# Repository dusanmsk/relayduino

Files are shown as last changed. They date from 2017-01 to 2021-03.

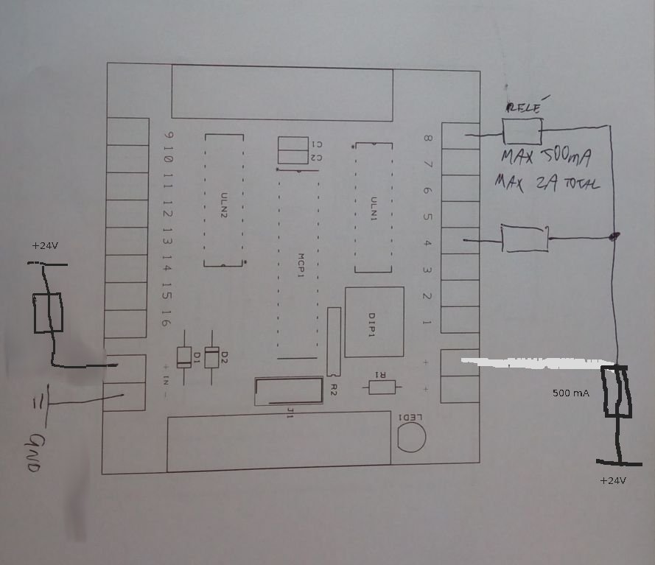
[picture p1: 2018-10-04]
outputmaster/wiring.jpg

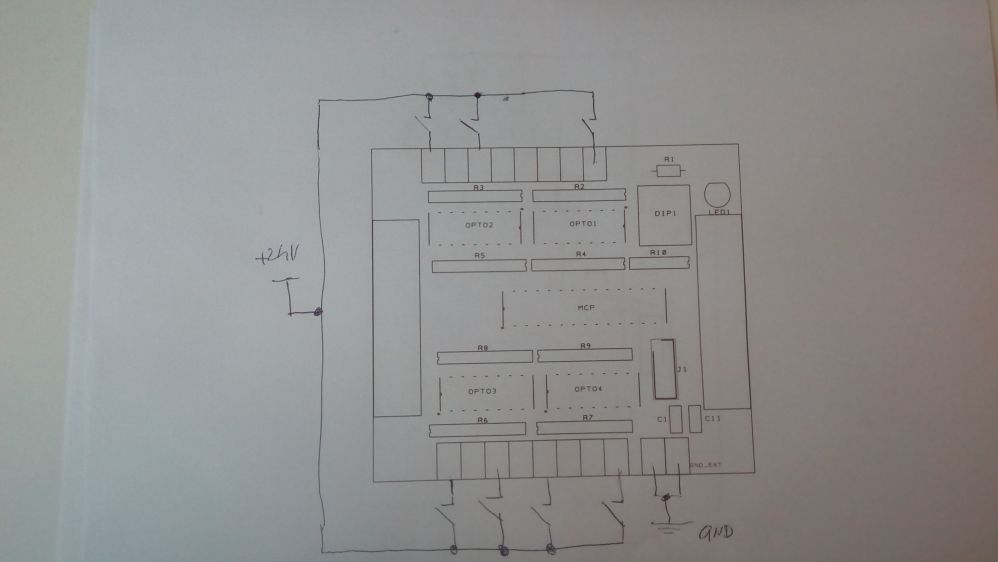
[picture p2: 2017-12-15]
inputmaster/wiring.jpg

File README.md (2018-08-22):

# Content

# Preparation

Arduino Nano is the actual platform. To sucessfully use arduino nano on masterboard you need
to flash optiboot bootloader to it. There is script which uploads optiboot to arduino nano using usbtiny in code/bootloader.
It requires usbtinyisp board connected to arduino nano and arduino ide to be installed. Flash take around 3 seconds.

When done, connect arduino nano using usb cable to pc and use XLoader utility to flash required firmware.
Use input or outputmaster_firmware_nano328.hex files, setup xloader as following:
- hex file: specify firmware file
- device: Uno (atmega 328)
- com port: where your nano is
- baud rade: 115200

Leds will flash during update.

To check nano was flashed succesfully, close xloader, then start arduino ide, choose board "Adruino/Genuino UNO", specify port
and start serial monitor at 9600 baud. If you will see messages such as:

Master board id: im0
Assigned address: 192.168.88.120
No ping - connection lost?
...

you have flashed sucessfully.

TODO

# How to connect

Connect input slave boards to input master board using XH cable. Same situation for output board

# Flashing firmware

On Windows use XLoader (http://xloader.russemotto.com/), on linux use avrdude. Download and flash right firmware depending on board you are flashing.

# Loxone

At first you need to create new virtual output, name "Relayduino output BUS", address /dev/udp/255.255.255.255/6666, separator ";". Then create new output command named "ping", command for ON: "ping"
and feed it with pulse generator configured 1 on 4 off seconds. Boards use this ping to detect network failures and this command is mandatory. When output board lost this command
for a while, it turns off all relays.

To drive single relay on masterboard=0, slaveboard=2, relay=3, create new output command with following configuration:
```
Command ON: om0 b2 r3 1
Command OFF: om0 b2 r3 0
First repetition: 30
Repetition interval: 30
Use as digital output
```

To receive signals from inputboards, create new udp virtual input named "Relayduino input BUS", udp receive port 5555. You should use udp monitor then to create commands from input packets.
If you would like to do so manually, structure of command is:
"im0 b3 i6 1" - means "Input 6 on slave board 3 of input masterboard 0 is ON".

Tip: if you would like to handle "long press" of button, you need to configure it as "im0 b3 i6 \v" and uncheck "use as digital input".

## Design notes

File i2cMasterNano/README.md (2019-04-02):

schematics and pcb moved to

https://easyeda.com/dusanmsk/i2cmaster_nano

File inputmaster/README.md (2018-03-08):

### Addressing
Dip switch has "mirrored logic", so to set right address you need to convert address to binary
and then switch 1 with 0.

So:
- 0 = on on on
- 1 = on on off
- 2 = on off on
- 3 = on off off
- 4 = off on on
- 5 = off on off
- 6 = off off on
- 7 = off off off

### BOM
ULN1, ULN2 = ULN2803A (+ optional socket DIP18)
DIP1 = 3 position dip switch
LED1 = green led
OPTO1,2,3,4 = K847ph + socket
R1 = 220
R2,3,6,7 = 4608X-102-103LF
R4,5,8,9 = 4608X-102-102LF
R10 = 4605x-101-102LF
J1 = 4 pin 2.54mm jst xh female
C1 = 100n keramic
C2 = 100p keramic
MCP1 =  MCP23017-E/SP (+ optional socket)
2x "ebay PCB Din C45 Rail Adapter 35mm"
2x 8pin 5.08 socket
1x 2pin 5.08 socket

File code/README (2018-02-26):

!!! Arduino nano:

Paste following text at end of:
c:\Users\X\AppData\Local\Arduino15\packages\arduino\hardware\avr\1.6.21\boards.txt

##############################################################

atmega328o.name=Optiboot Nano328
atmega328o.upload.tool=avrdude
atmega328o.upload.protocol=arduino
atmega328o.upload.maximum_size=32256
atmega328o.upload.speed=115200
atmega328o.bootloader.tool=avrdude
atmega328o.bootloader.low_fuses=0xff
atmega328o.bootloader.high_fuses=0xde
atmega328o.bootloader.extended_fuses=0x05
atmega328o.bootloader.path=optiboot
atmega328o.bootloader.file=optiboot/optiboot_atmega328.hex 
atmega328o.bootloader.unlock_bits=0x3F
atmega328o.bootloader.lock_bits=0x0F
atmega328o.build.mcu=atmega328p
atmega328o.build.f_cpu=16000000L
atmega328o.build.board=AVR_ATMEGA328O
atmega328o.build.core=arduino:arduino
atmega328o.build.variant=arduino:eightanaloginputs

############################################################## 

... then reflash bootloader. Then use board as "Optiboot Nano328".

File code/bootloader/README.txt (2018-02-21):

To use hardware watchdog on arduino nano you must flash custom optiboot bootloader.
Here is a copy of bootloader from arduino toolchain and simple script that flash it using usbtiny.

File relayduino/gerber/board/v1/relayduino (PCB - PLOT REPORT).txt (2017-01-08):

PLOT REPORT
-----------

Report File:        G:\work\relayduino\relayduino\relayduino (PCB - PLOT REPORT).txt
Report Written:     Sunday, January 08, 2017
Design Path:        G:\work\relayduino\relayduino\relayduino.pcb
Design Title:       
Created:            11.12.2016 19:21:11
Last Saved:         8.1.2017 19:48:49
Editing Time:       1445 min
Units:              mm (precision 2)

Device Settings
===============

Gerber Settings
===============

    Leading zero suppression.
    G01 assumed throughout.
    Line termination <*> <CR> <LF>.
    3.5 format absolute inches.

    Format commands defined in Gerber file.
    Aperture table defined in Gerber file.
    Hardware arcs allowed.

Drill Settings
==============

    Excellon Format 1    Format 3.5 absolute in mm.
    No zero suppression.

Plots Output
============

Gerber Output
=============

G:\work\relayduino\relayduino\relayduino - Top Documentation.gbr

    Layers:
    ---------------------
    Top Documentation

    D-Code Shape  (thou)
    -----------------------
    D21    Round 1.00

Gerber Output
=============

G:\work\relayduino\relayduino\relayduino - Top Silkscreen.gbr

    Layers:
    ------------------
    Top Silkscreen

    D-Code Shape  (thou)
    -----------------------
    D11    Round 5.00
    D12    Round 6.00
    D13    Round 3.00
    D14    Round 10.00
    D21    Round 1.00

Gerber Output
=============

G:\work\relayduino\relayduino\relayduino - Bottom Copper.gbr

    Layers:
    -----------------
    Bottom Copper

    D-Code Shape  (thou)
    -----------------------
    D18    Square 60.00
    D70    Round 25.00
    D71    Round 15.00
    D20    Round 50.00
    D23    Square 60.00
    D24    Round 60.00
    D25    Round 80.00
    D76    Round 7.87
    D77    Square 54.00
    D78    Round 54.00
    D79    Round 52.76

Gerber Output
=============

G:\work\relayduino\relayduino\relayduino - Bottom Copper (Paste).gbr

    Layers:
    -----------------
    Bottom Copper

    D-Code Shape  (thou)
    -----------------------

Gerber Output
=============

G:\work\relayduino\relayduino\relayduino - Bottom Solder Mask.gbr

    Layers:
    ----------------------
    Bottom Solder Mask

    D-Code Shape  (thou)
    -----------------------
    D23    Square 60.00
    D24    Round 60.00
    D80    Round 124.11
    D81    Square 66.00
    D82    Square 66.00
    D83    Round 66.00
    D84    Round 86.00
    D85    Round 58.76

NC Drill Output
===============

G:\work\relayduino\relayduino\relayduino - Drill Data - [Through Hole].drl

    Output:
    ---------------------------
    Plated Round Drill Holes
    Plated Slots
    Plated Board Outlines

    Tool  Size         Count   ID
    ------------------------------------
    T001  000.03200 in 80    A
    T002  000.03307 in 36    J
    T003  000.03400 in 10    I
    T004  000.03500 in 43    B
    T005  000.05000 in 42    F
    T006  000.11811 in 4     G
    ------------------------------------
    Total              215
    ------------------------------------

G:\work\relayduino\relayduino\relayduino - Drill Data - [Through Hole] (Unplated).drl

    Output:
    -----------------------------
    Unplated Round Drill Holes
    Unplated Slots
    Unplated Board Outlines

    Tool  Size         Count   ID
    ------------------------------------
    T001  000.02500 in 1
    ------------------------------------
    Total              1
    ------------------------------------

Gerber Output
=============

G:\work\relayduino\relayduino\relayduino - Drill Ident Drawing - [Through Hole].gbr

    Layers:
    ------------------
    [Through Hole]

Drill Ident Drawing
===================

    Drill Plated Size Shape ID
    -----------------------------------
    32    Y      100  Round A
    35    Y      100  Round B
    50    Y      100  Round F
    118   Y      100  Round G
    34    Y      100  Round I
    33    Y      100  Round J

    D-Code Shape  (thou)
    -----------------------
    D10    Round 100.00
    D11    Round 5.00

End Of Report.

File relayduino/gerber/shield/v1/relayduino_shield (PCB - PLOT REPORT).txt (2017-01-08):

PLOT REPORT
-----------

Report File:        G:\work\relayduino\relayduino\relayduino_shield (PCB - PLOT REPORT).txt
Report Written:     Sunday, January 08, 2017
Design Path:        G:\work\relayduino\relayduino\relayduino_shield.pcb
Design Title:       
Created:            11.12.2016 22:00:14
Last Saved:         18.12.2016 11:29:52
Editing Time:       301 min
Units:              mm (precision 2)

Device Settings
===============

Gerber Settings
===============

    Leading zero suppression.
    G01 assumed throughout.
    Line termination <*> <CR> <LF>.
    3.5 format absolute inches.

    Format commands defined in Gerber file.
    Aperture table defined in Gerber file.
    Hardware arcs allowed.

Drill Settings
==============

    Excellon Format 1    Format 3.5 absolute in mm.
    No zero suppression.

Plots Output
============

    Plot Job: "G:\work\relayduino\relayduino\relayduino_shield.mop"

Gerber Output
=============

G:\work\relayduino\relayduino\relayduino_shield - Top Silkscreen.gbr

    Layers:
    ------------------
    Top Silkscreen

    D-Code Shape  (thou)
    -----------------------

Gerber Output
=============

G:\work\relayduino\relayduino\relayduino_shield - Top Copper.gbr

    Layers:
    --------------
    Top Copper

    D-Code Shape  (thou)
    -----------------------
    D18    Square 60.00
    D70    Round 25.00
    D22    Round 60.00
    D26    Round 56.00

Gerber Output
=============

G:\work\relayduino\relayduino\relayduino_shield - Top Copper (Resist).gbr

    Layers:
    --------------
    Top Copper

    D-Code Shape  (thou)
    -----------------------
    D27    Round 70.00
    D28    Square 70.00

Gerber Output
=============

G:\work\relayduino\relayduino\relayduino_shield - Top Copper (Paste).gbr

    Layers:
    --------------
    Top Copper

    D-Code Shape  (thou)
    -----------------------

Gerber Output
=============

G:\work\relayduino\relayduino\relayduino_shield - Bottom Copper.gbr

    Layers:
    -----------------
    Bottom Copper

    D-Code Shape  (thou)
    -----------------------
    D18    Square 60.00
    D70    Round 25.00
    D22    Round 60.00
    D26    Round 56.00

Gerber Output
=============

G:\work\relayduino\relayduino\relayduino_shield - Bottom Copper (Resist).gbr

    Layers:
    -----------------
    Bottom Copper

    D-Code Shape  (thou)
    -----------------------
    D27    Round 70.00
    D28    Square 70.00

Gerber Output
=============

G:\work\relayduino\relayduino\relayduino_shield - Bottom Copper (Paste).gbr

    Layers:
    -----------------
    Bottom Copper

    D-Code Shape  (thou)
    -----------------------

Gerber Output
=============

G:\work\relayduino\relayduino\relayduino_shield - Bottom Silkscreen.gbr

    Layers:
    ---------------------
    Bottom Silkscreen

    D-Code Shape  (thou)
    -----------------------
    D14    Round 10.00

NC Drill Output
===============

G:\work\relayduino\relayduino\relayduino_shield - Drill Data - [Through Hole].drl

    Output:
    ---------------------------
    Plated Round Drill Holes
    Plated Slots
    Plated Board Outlines

    Tool  Size         Count   ID
    ------------------------------------
    T001  000.03200 in 26    A
    T002  000.03500 in 88    B
    ------------------------------------
    Total              114
    ------------------------------------

G:\work\relayduino\relayduino\relayduino_shield - Drill Data - [Through Hole] (Unplated).drl

    Output:
    -----------------------------
    Unplated Round Drill Holes
    Unplated Slots
    Unplated Board Outlines

    Tool  Size         Count   ID
    ------------------------------------
    T001  000.02500 in 1
    ------------------------------------
    Total              1
    ------------------------------------

Gerber Output
=============

G:\work\relayduino\relayduino\relayduino_shield - Drill Ident Drawing - [Through Hole].gbr

    Layers:
    ------------------
    [Through Hole]

Drill Ident Drawing
===================

    Drill Plated Size Shape ID
    -----------------------------------
    32    Y      100  Round A
    35    Y      100  Round B

    D-Code Shape  (thou)
    -----------------------
    D10    Round 100.00
    D11    Round 5.00

End Of Report.

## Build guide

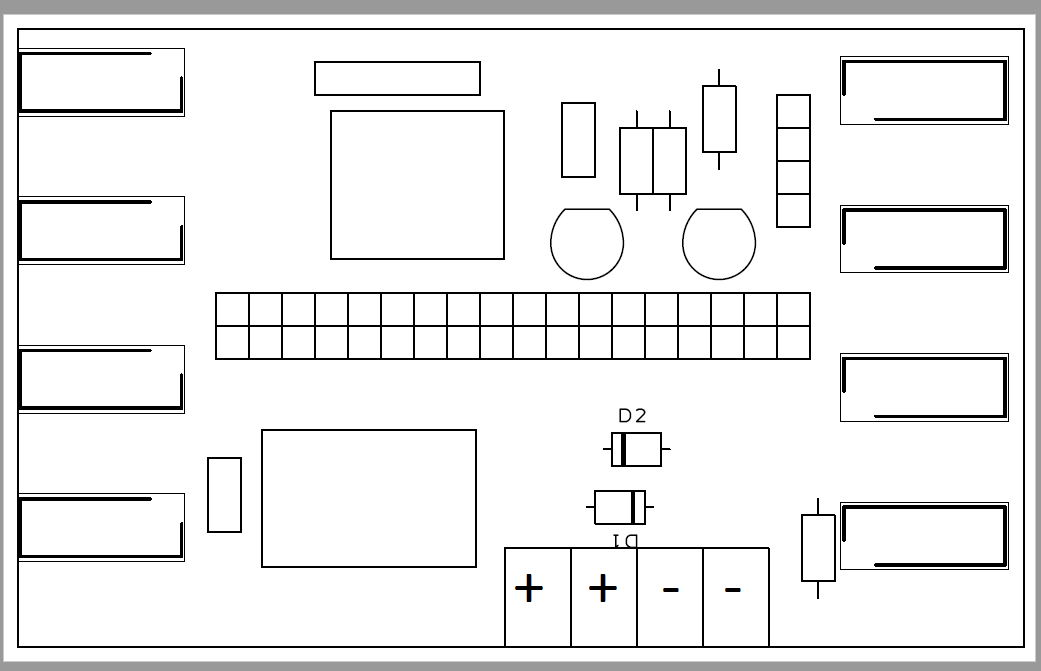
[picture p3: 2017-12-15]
i2cMasterMega/wiring.png

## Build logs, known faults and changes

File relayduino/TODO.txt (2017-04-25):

- blokovacie kondiky
- ledky per vystup?

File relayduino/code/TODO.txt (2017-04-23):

Inicializacia zariadenia:

- po cistom flashi je uplne blbe
- pri starte podrzat tlacitko, prepne sa do rezimu nastavenia adresy (zacne blikat ledka)
- tlacitkom natukat cislo dosky v case 30 sekund
- po 30 sec sa cislo dosky ulozi do eeprom a doska sa restartuje

- nabehne doska, nacita cislo dosky z eeprom (napr. 8)
- posiela UDP broadcast "hello board 8"
- loxone odpovie broadcast udp s konfiguraciou pre dosku vo formate:
  ip=192.168.100.8/24
  miniserver=192.168.100.10

Zivot dosky:
- caka na udp pakety vo formate "obX pY Z", kde X je cislo dosky, Y je cislo vystupneho portu (1-56) a Z je hodnota 0/1. Napr "ob2 p12 1".
- pokial pride "p12 1", zopne sa rele 12
- pokial pride "p12 0", rozopne sa rele 12
- pokial je doska v rezime "countdown", vyzaduje periodicke posielanie prikazov "p12 1". Pokial nedojde k doruceniu do urciteho casu, prepne vystup do 0. Implementovat counterom a casovym intervalom.

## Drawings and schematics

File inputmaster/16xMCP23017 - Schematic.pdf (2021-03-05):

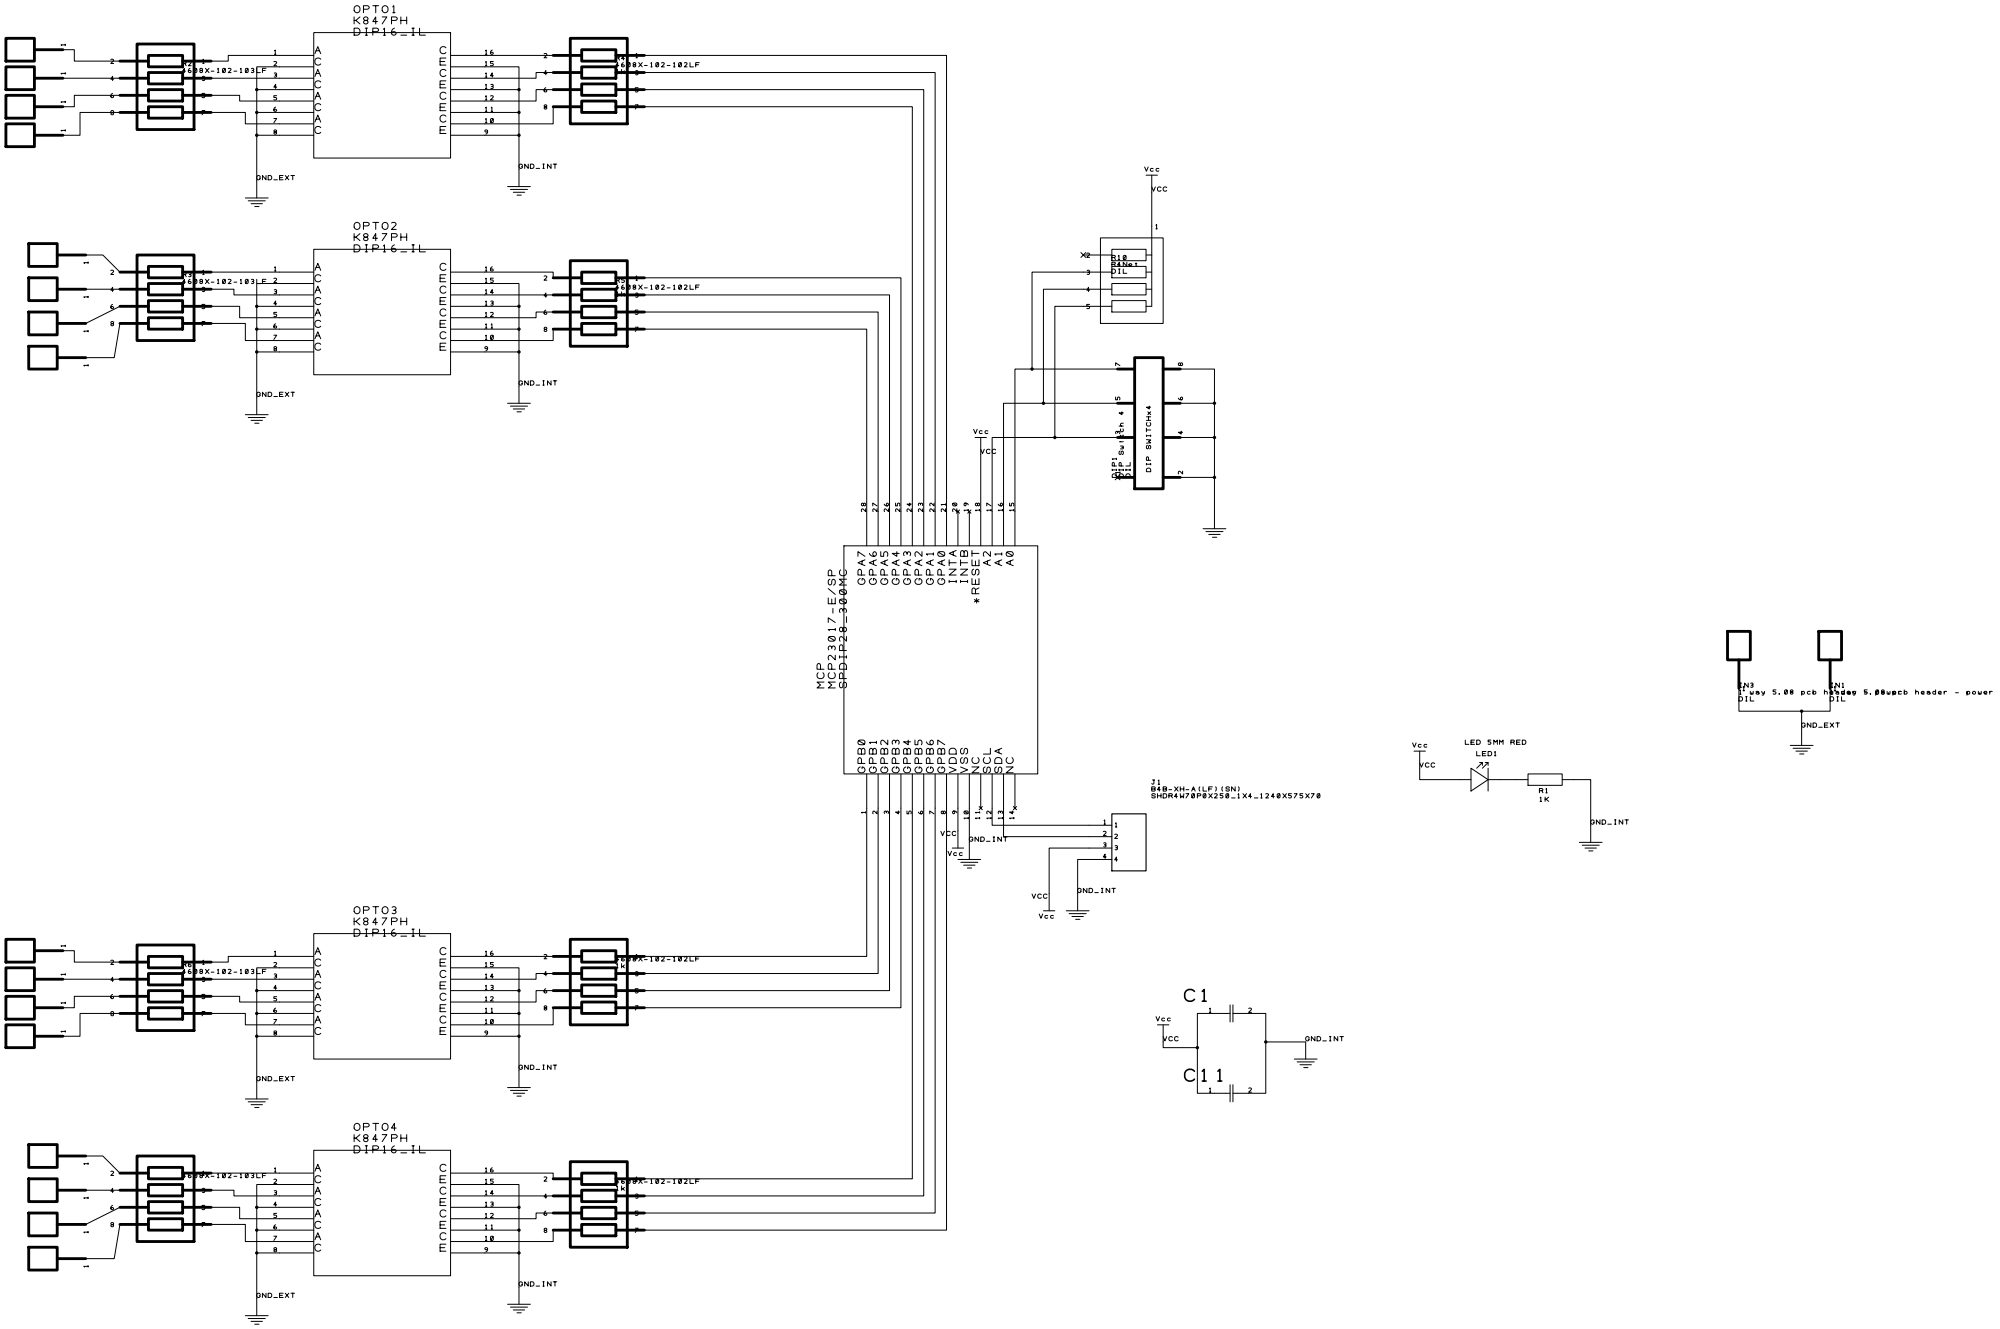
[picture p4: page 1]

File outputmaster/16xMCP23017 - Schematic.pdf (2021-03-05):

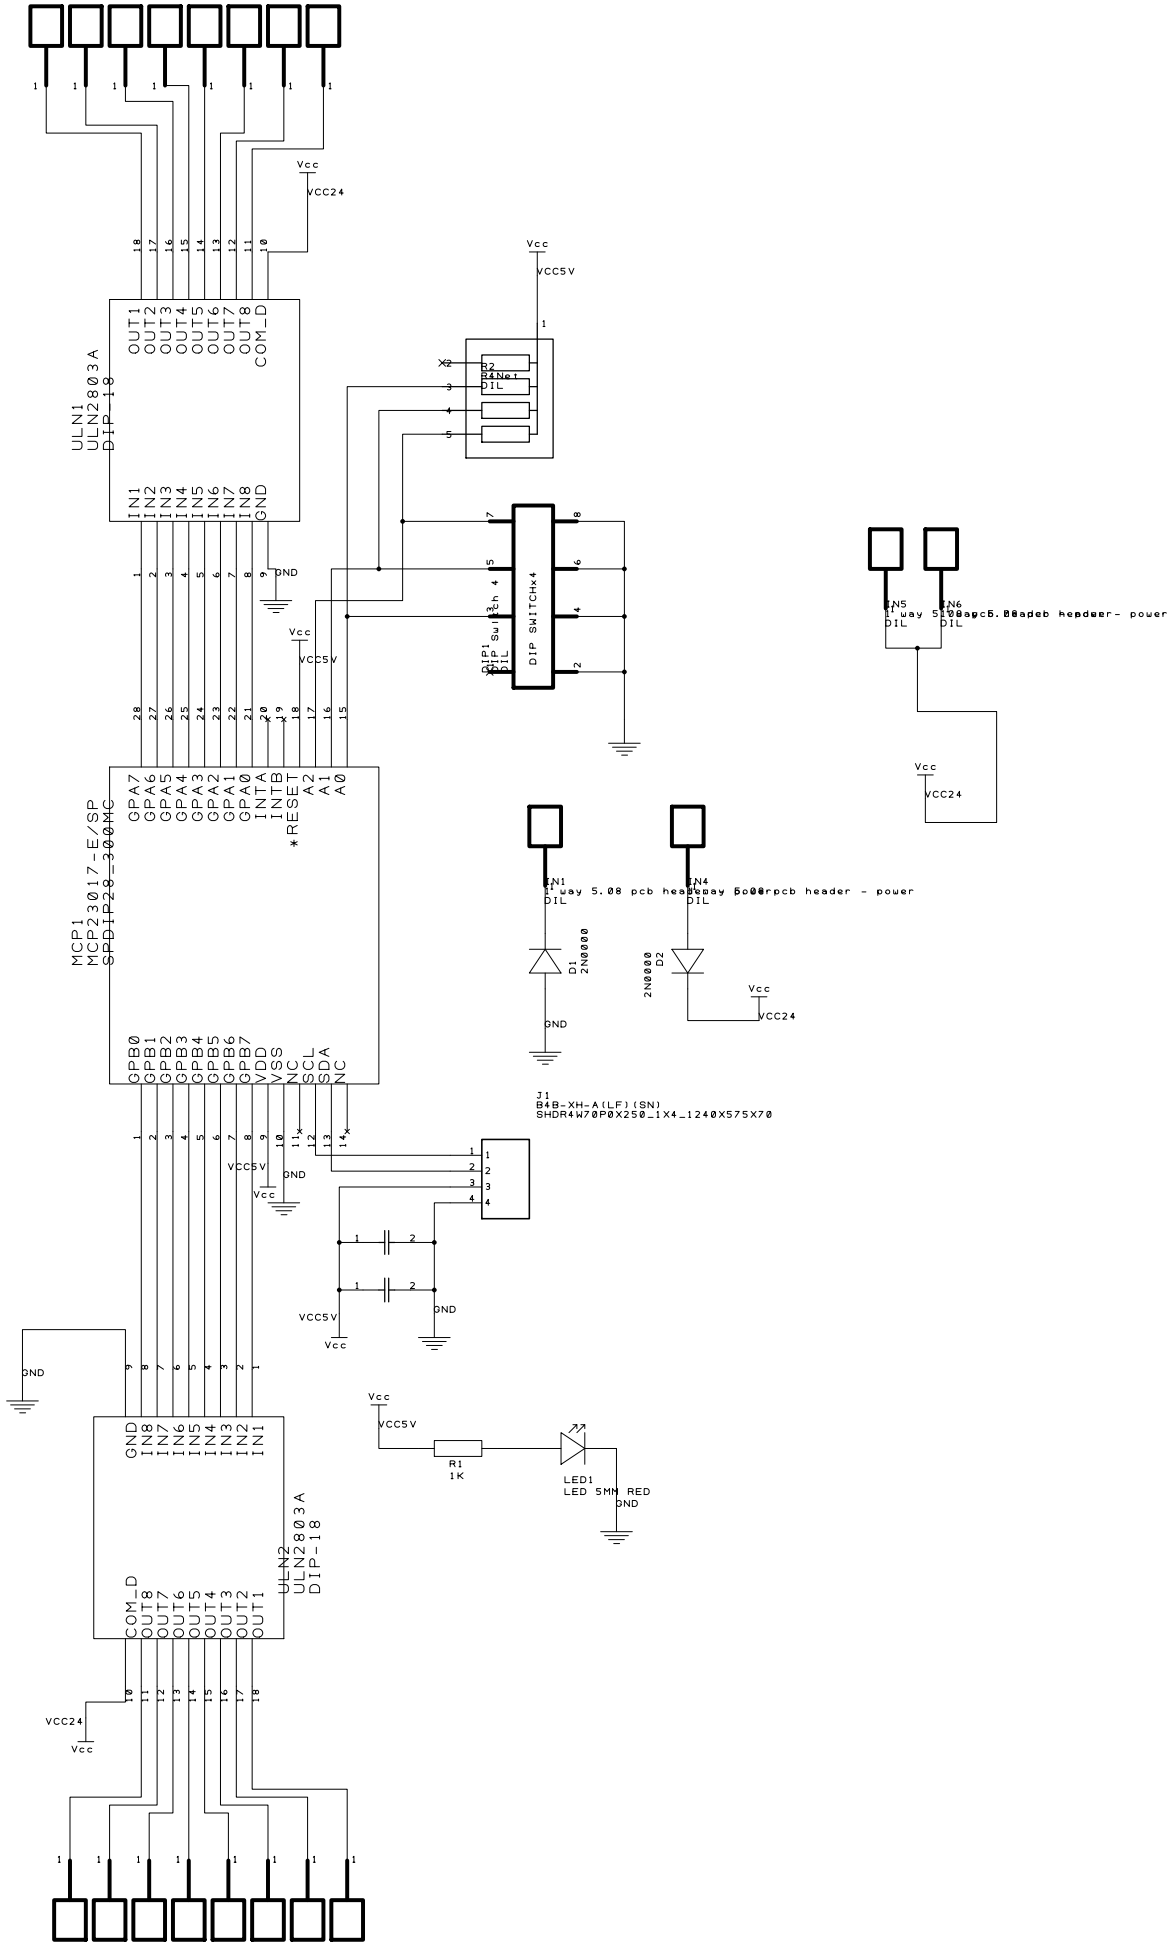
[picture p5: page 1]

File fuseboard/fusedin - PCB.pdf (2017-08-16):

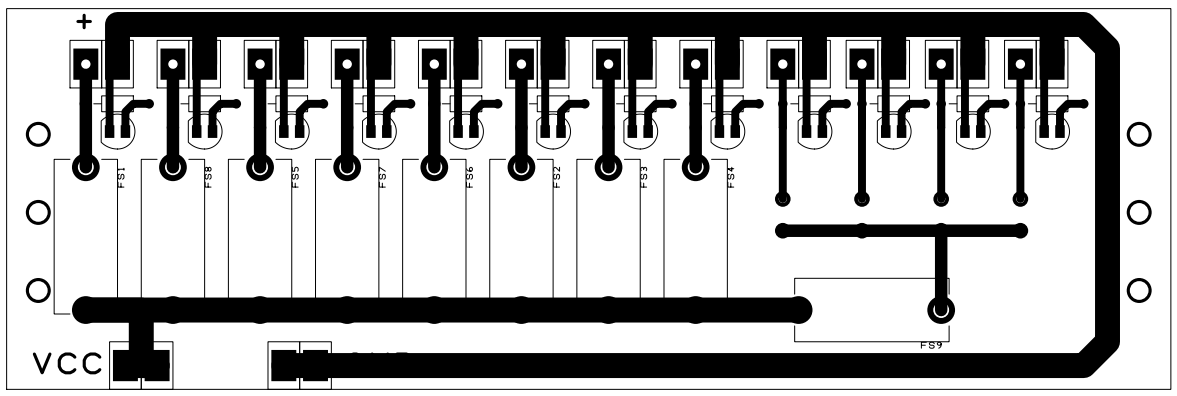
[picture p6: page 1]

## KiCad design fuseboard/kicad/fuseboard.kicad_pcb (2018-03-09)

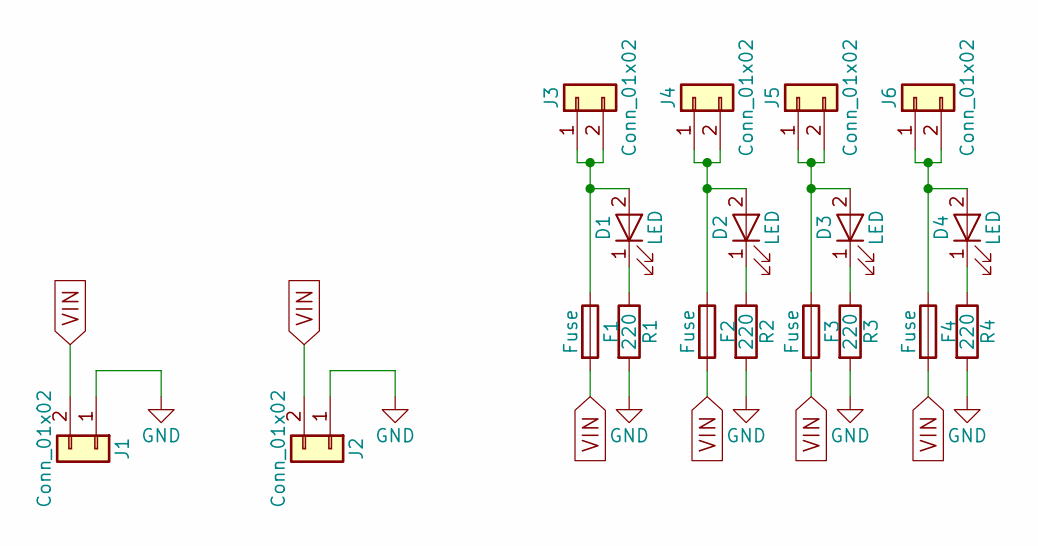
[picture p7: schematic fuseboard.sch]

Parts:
D1, D2, D3, D4: LED; LED_D3.0mm
F1, F2, F3, F4: Fuse; Fuseholder5x20_horiz_open_Schurter_0031_8201
J1, J2, J3, J4, J5, J6: Conn_01x02; MSK-2x5.08_terminal
R1, R2, R3, R4: 220; R_Axial_DIN0207_L6.3mm_D2.5mm_P10.16mm_Horizontal

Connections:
GND: J1.1, J2.1, R1.2, R2.2, R3.2, R4.2
unnamed: D1.1 (K), R1.1
unnamed: D1.2 (A), F1.1, J3.1, J3.2
unnamed: D2.1 (K), R2.1
unnamed: D2.2 (A), F2.1, J4.1, J4.2
unnamed: D3.1 (K), R3.1
unnamed: D3.2 (A), F3.1, J5.1, J5.2
unnamed: D4.1 (K), R4.1
unnamed: D4.2 (A), F4.1, J6.1, J6.2
VIN: F1.2, F2.2, F3.2, F4.2, J1.2, J2.2

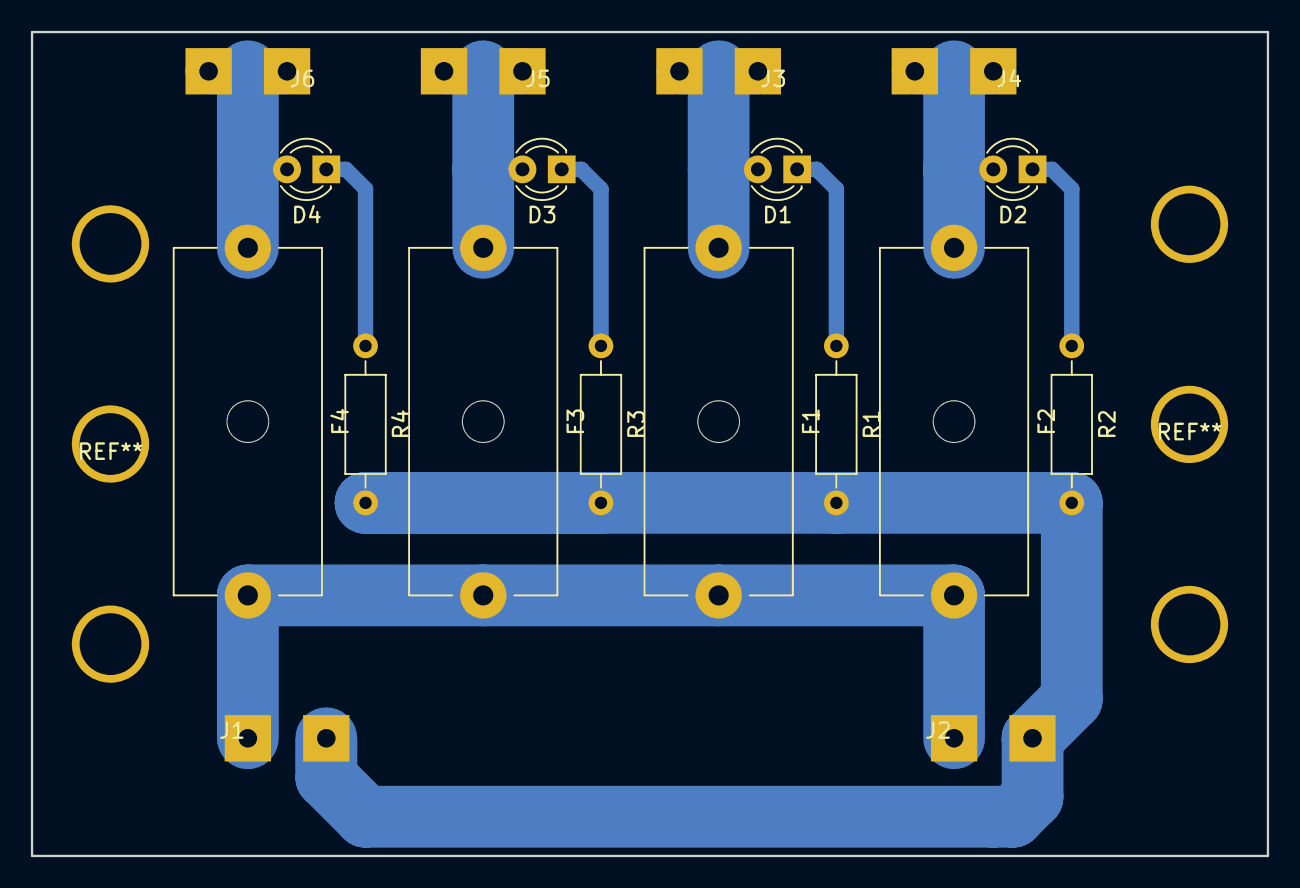
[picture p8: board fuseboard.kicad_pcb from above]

Board: 2 copper layers, 80.0 x 53.3 mm, 18 parts (0 on the bottom side), 10 nets.

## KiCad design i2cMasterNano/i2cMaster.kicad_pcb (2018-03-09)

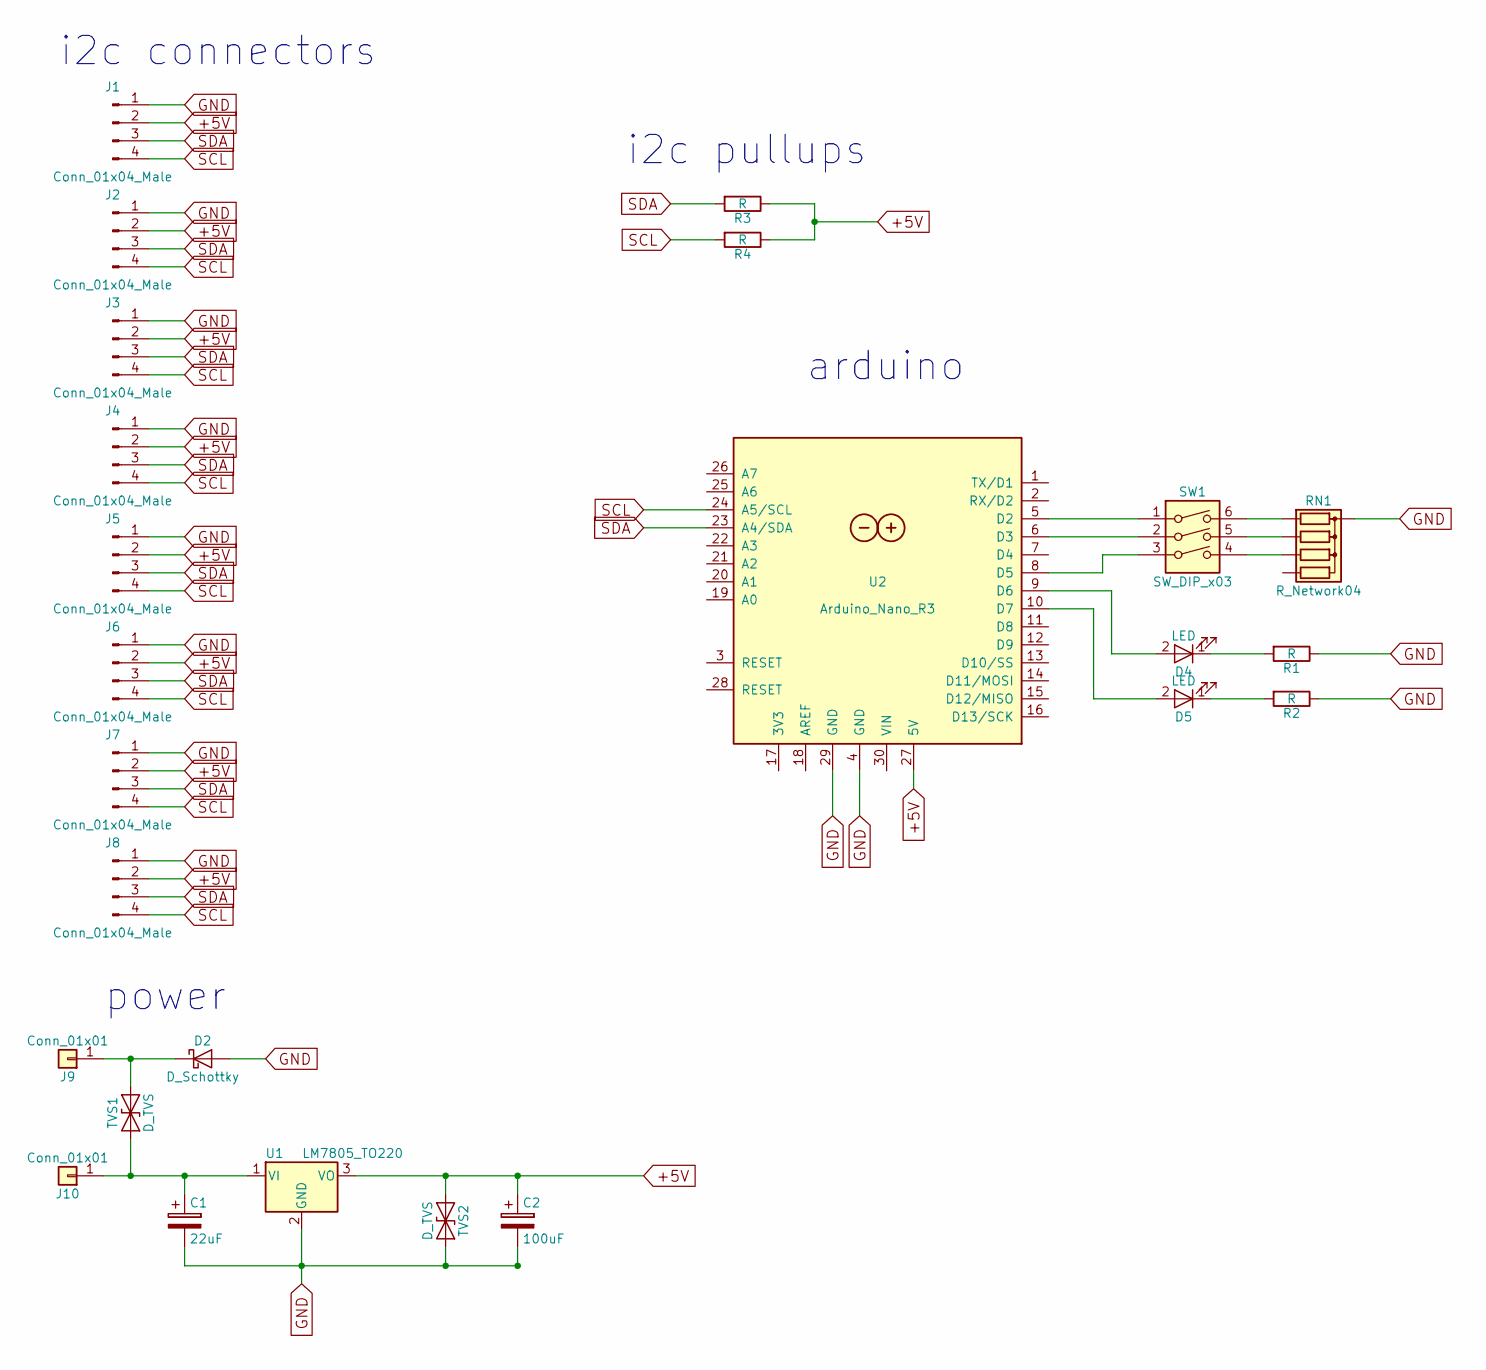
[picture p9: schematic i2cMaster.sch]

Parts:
C1: 22uF; CP_Radial_D5.0mm_P2.50mm
C2: 100uF; CP_Radial_D10.0mm_P3.50mm
D2: D_Schottky; D_5W_P12.70mm_Horizontal
D4, D5: LED; LED_D3.0mm
J1, J2, J3, J4, J5, J6, J7, J8: Conn_01x04_Male; JST_EH_B04B-EH-A_04x2.50mm_Straight
J9, J10: Conn_01x01; MSK-5.08_terminal
R1, R2, R3, R4: R; R_Axial_DIN0207_L6.3mm_D2.5mm_P10.16mm_Horizontal
RN1: R_Network04; R_Array_SIP5
SW1: SW_DIP_x03; SW_DIP_x3_W7.62mm_Slide
TVS1, TVS2: D_TVS; D_5W_P12.70mm_Horizontal
U1: LM7805_TO220; TO-220
U2: Arduino_Nano_R3; Arduino_Nano_Ethernet

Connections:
+5V: C2.1, J1.2, J2.2, J3.2, J4.2, J5.2, J6.2, J7.2, J8.2, R3.1, R4.1, TVS2.1 (A1), U1.3 (VO), U2.27 (5V)
GND: C1.2, C2.2, D2.2 (A), J1.1, J2.1, J3.1, J4.1, J5.1, J6.1, J7.1, J8.1, R1.1, R2.1, RN1.1 (common), TVS2.2 (A2), U1.2 (GND), U2.4 (GND), U2.29 (GND)
unnamed: C1.1, J10.1, TVS1.1 (A1), U1.1 (VI)
unnamed: D2.1 (K), J9.1, TVS1.2 (A2)
unnamed: D4.1 (K), R1.2
unnamed: D4.2 (A), U2.9 (D6)
unnamed: D5.1 (K), R2.2
unnamed: D5.2 (A), U2.10 (D7)
unnamed: RN1.2 (R1), SW1.6
unnamed: RN1.3 (R2), SW1.5
unnamed: RN1.4 (R3), SW1.4
unnamed: SW1.1, U2.5 (D2)
unnamed: SW1.2, U2.6 (D3)
unnamed: SW1.3, U2.8 (D5)
SCL: J1.4, J2.4, J3.4, J4.4, J5.4, J6.4, J7.4, J8.4, R4.2, U2.24 (A5/SCL)
SDA: J1.3, J2.3, J3.3, J4.3, J5.3, J6.3, J7.3, J8.3, R3.2, U2.23 (A4/SDA)

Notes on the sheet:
i2c pullups
i2c connectors
power
arduino

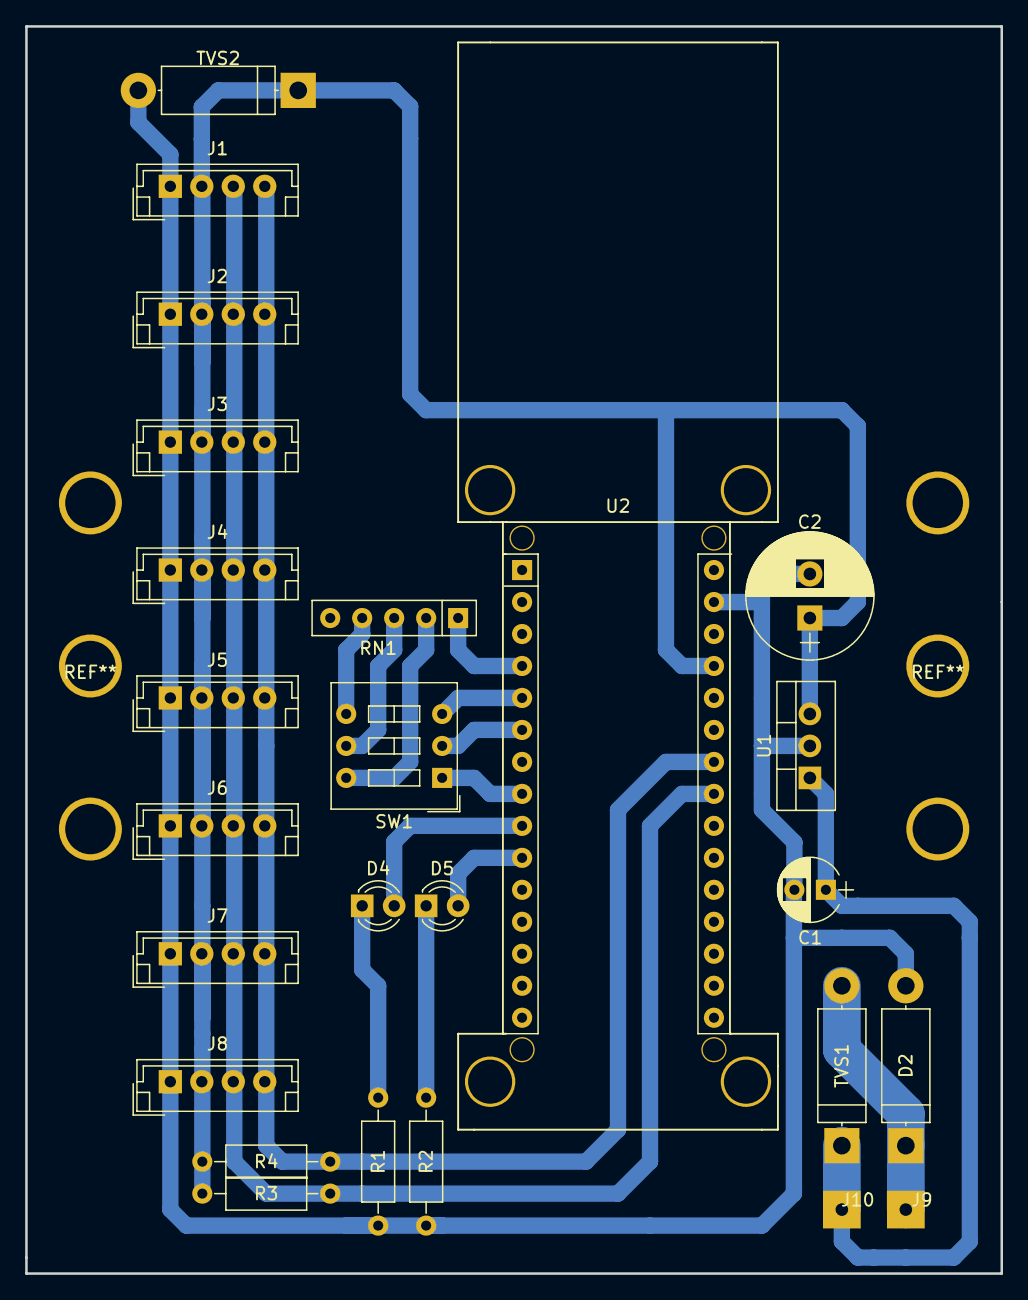
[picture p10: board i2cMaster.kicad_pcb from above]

Board: 2 copper layers, 77.5 x 99.1 mm, 25 parts (0 on the bottom side), 16 nets.

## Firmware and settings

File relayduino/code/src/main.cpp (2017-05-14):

#define DATA_PIN  2
#define OE_PIN 3
#define RCLK_PIN  4
#define SRCLK_PIN  5
#define CONFIG_BUTTON_PIN 7
#define LED_PIN A5    // TODO move to A7
#define BAUDRATE 115200

#include "Arduino.h"
#include "Board.h"
#include "main.h"
#include "dbg.h"
#include "Configuration.h"
#include "EEPROM.h"
#include "Network.h"
#include "OutputPorts.h"
#include "595.h"
#include "Timer.h"

#include <avr/io.h>
//#include <avr/wdt.h>

#include "Network.h"


byte mac[] = {0xDE, 0xAD, 0xBE, 0xEF, 0xFE, 0};
const int listenPort = 5555;


Board board(LED_PIN, CONFIG_BUTTON_PIN);
Configuration cfg;
OutputPorts outputPorts(10);
Serial595 s595(DATA_PIN, OE_PIN, RCLK_PIN, SRCLK_PIN);
Network network;

void shiftRelays() {
  int portIndex = 56;
  for(int i = 0; i < 8; i++) {
    for(int u = 0; u < 7; u++) {
      bool value = outputPorts.getValue(portIndex--);
      s595.writeBit(value);
    }
    s595.writeBit(false);  // bit 8 of each shift register is not used/connected
  }

  s595.propagateData();
  s595.setOutputEnable(true);
}


void initialize() {

  // initialize board
  s595.setOutputEnable(false);
  board.initialize();
  board.blinkBoardId();

  // initialize network
  mac[5] = (0xED + board.getBoardId());
  IPAddress listenIpAddress = IPAddress(192, 168, 100, 150 + board.getBoardId());
  network.begin(mac, listenIpAddress);
}


void setup() {

  Serial.begin(BAUDRATE);
  delay(2000);    // do initial sleep (give user time to move finger from reset to config button)
  dbg("Start");

  initialize();

  dbg("Initialized");
}



Timer relaysTimeoutTimer;
Timer boardLedTimeoutTimer;
int boardId, relayId, relayValue, parsedArgs;
void loop() {

  // receive packet
  if(network.receiveUdp(listenPort)) {
    const char* packet = network.getReceivedPacket();
    parsedArgs = sscanf(packet, "b%d r%d %d", &boardId ,&relayId, &relayValue);
    if(parsedArgs == 3 && boardId == board.getBoardId()) {
        board.setLed(1);
        if(relayValue > 0) {
          outputPorts.setOn(relayId);
        } else {
          outputPorts.setOff(relayId);
        }
        shiftRelays();
      }
    }

    // TODO process this only when in "timeout" mode
    // process relay timeouts
    if(relaysTimeoutTimer.isOver()) {
      int howTimeout = outputPorts.processTimeouts();
      if(howTimeout > 0) {
        shiftRelays();
      }
      relaysTimeoutTimer.sleep(1000);
    }

    if(boardLedTimeoutTimer.isOver()) {
      board.setLed(0);
      boardLedTimeoutTimer.sleep(50);
    }


}

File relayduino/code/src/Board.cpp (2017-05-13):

#include "Arduino.h"
#include "Board.h"
#include "dbg.h"
#include "Network.h"
#include "EEPROM.h"

#define EEPROM_BOARD_ID_OFFSET 0


Board::Board(int ledPin, int configButtonPin) {
  this->configButtonPin = configButtonPin;
  this->ledPin = ledPin;
  pinMode(ledPin, OUTPUT);
  pinMode(configButtonPin, INPUT_PULLUP);
}

bool Board::isConfigButtonPressed() {
   return ! digitalRead(configButtonPin);
}

void Board::blinkLed(int timeMs) {
  dbg("LED ON");
  setLed(HIGH);
  delay(timeMs);
  setLed(LOW);
  dbg("LED OFF");
  delay(timeMs);
}

void Board::setLed(int value) {
  digitalWrite(ledPin, value > 0 ? HIGH : LOW);
}

void Board::initialize() {

  runInitialConfigFlow();

  boardId = EEPROM.read(EEPROM_BOARD_ID_OFFSET);
  boardIdStr = String("board_") + String(boardId, DEC);
  dbgf("Board id: %d", boardId);




}

/**
  Initial configuration flow. Board gives user a chance to reconfigure board address using configuration button.
  Press and hold this button during board boot process until signalization led will not shine for 3 seconds.
  Then wait until it will start to pulse. Each pulse increments board id by 1.
  After you set the board id, release button and wait a while. Board will pulse new id again in shorter time and then
  board id is stored in eeprom and board continues to boot normally.
**/
void Board::runInitialConfigFlow() {

  dbg("Running initial config flow")

  // check if 'config' button is pressed for 5 seconds
  for(int i = 0; i < 50; i++) {
    if(!isConfigButtonPressed()) {
      dbg("Config button not hold, continue with normal start")
      return;
    }
    delay(10);
  }

    // blink led and count hits of config button until it is not released
    setLed(1);
    delay(3000);
    setLed(0);
    delay(1000);

    // tick and count ticks when button is still hold, break when button is released
    boardId = 0;
    for(int i = 0; i < 255; i++) {
      if(!isConfigButtonPressed()) {
        dbgf("Break %d", i);
        break;
      }
      blinkLed(30);
      boardId++;
      delay(1000);
    }

    // now flash led boardId-times to give user feedback and then store boardid into eeprom
    dbgf("Board id is %d" , boardId);
    delay(2000);
    dbgf("Storing board id %d to eeprom", boardId);
    EEPROM.write(EEPROM_BOARD_ID_OFFSET, boardId);
}

void Board::blinkBoardId() {
  for(int i = 0; i < boardId; i++) {
    blinkLed(30);
    delay(200);
  }
}

void Board::awaitBoardConfiguration() {

  /**
    Board initialization hanshake looks like this:
    1. board assign ip address statically - by board id (which is configurable by config button). This address is always 192.168.99.X where X is 100+boardId
    2. board then sends "hello boardX" udp broadcast
    2. loxone then must respond with "boardX hi ipAddress", where ipAddress is address where board will then bind to
  **/

  dbg("Requesting board configuration");

  uint8_t mac[6] = {0x00,0x01,0x02,0x03,0x04,100+boardId};
  Network net;
  //net.begin(mac, IPAddress(192,168,99,100+boardId));
  net.begin(mac, IPAddress(255,255,255,255));

  while(true) {
    net.sendUdp(IPAddress(255,255,255,255), 5000, "hello " + boardIdStr);

    // TODO receive, then return, else sleep
    for (int i = 0; i < 100; i++) {
      if(net.receiveUdp(5000)) {
        String response = net.getReceivedPacket();
        // TODO if response starts with "hi", parse line-by line then look for board_X for current board. Then parse ip address.
        dbg("Response is:");
        dbg(response);
      }
      delay(50);
    }

    delay(500);
  }

  /*
  EthernetUDP udpRecv;
  EthernetUDP udpSend;

  String boardAddressStr = String("board") + String(cfg.boardId, DEC);

  udpSend.beginPacket(IPAddress(255,255,255,255),5000);
  udpSend.write("hello ");
  udpSend.write(boardAddressStr);
  udpSend.flush();

  success = udpRecv.begin(5000);

  char buf[64];

while (true) {
  int packetSize = udpRecv.parsePacket();
     if (packetSize) {
         memset(buf, 0, sizeof(buf));
         udpRecv.read(buf, sizeof(buf));
         String cmd = String(buf);
         if (cmd.startsWith(boardAddressStr)) {
             cmd.replace(boardAddressStr, "");
             cmd.trim();
             dbgf("Received initial configuration: %s", cmd);
             // TODO parse board ip address
             // TODO get loxone ip address from config packet
             return;
         }
       }

    //delay(1000);
  }
  */
}

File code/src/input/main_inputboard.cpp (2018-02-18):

#include "../common/Globals.h"
#include "../common/MasterBoard.h"
#include "../common/dbg.h"
#include "InputBoard.h"
#include "../common/networking.h"

#include <SPI.h>
#include <Wire.h>
#include "../common/mcp.h"

//#include "Timer.h"

/*
 TODO:
 - setup main board (casom)
 - find all input boards
 */

char recvBuffer[recvBufferSize];

MasterBoard masterBoard;
Timer pingTimer;

char masterBoardIdStr[5];
int masterBoardIdStrLen;

#define NUM_OF_INPUT_BOARDS 8

InputBoard* connectedBoards[NUM_OF_INPUT_BOARDS];
Adafruit_MCP23017 mcp;

void (*uglyResetTheBoard)(void) = 0; //declare reset function @ address 0 - ugly hard hack that works
void setup() {

	Serial.begin(9600);
	//while (!Serial);

	int masterBoardId = masterBoard.getId();
	snprintf(masterBoardIdStr, 5, "im%d", masterBoardId);
	masterBoardIdStrLen = strlen(masterBoardIdStr);

	dbg("Master board id: %s", masterBoardIdStr);

	// input masterBoards starts 192.168.100.120
	initNetwork(120 + masterBoardId);

	// find input boards
	int error;
	Wire.begin();
	for (int adr = 0; adr < NUM_OF_INPUT_BOARDS; adr++) {
		connectedBoards[adr] = 0;
		Wire.beginTransmission(adr + MCP23017_ADDRESS);
		error = Wire.endTransmission();
		if (error == 0) {
			dbg("Found input board at address: %d", adr);
			connectedBoards[adr] = new InputBoard(&mcp, adr);
		}
	}

	masterBoard.initBlink();

	// send hello
	char buf[32];
	snprintf(buf, 32, "hello im%d", masterBoardId);
	send(buf);
}

void sendCommand(int masterBoardId, int inputBoardId, int inputId, int value) {
	char buf[32];
	snprintf(buf, 32, "im%d b%d i%d %d", masterBoardId, inputBoardId,
			inputId + 1, value);
	dbg("Sending %s", buf);
	send(buf);
}

boolean isOnline;
int failedPings = 0;

void loop() {

	// iterate over all connected boards
	for (int address = 0; address < NUM_OF_INPUT_BOARDS; address++) {
		if (connectedBoards[address]) {
			InputBoard* inputBoard = connectedBoards[address];
			int responses[16];
			inputBoard->readInputs(responses);
			for (int i = 0; i < 16; i++) {
				if (responses[i] != 0) {
					masterBoard.blinkInfoLed(30);
					sendCommand(masterBoard.getId(), inputBoard->getId(), i,
							responses[i] == -1 ? 0 : 1);
				}
			}
		}
	}

	// process ping
	if (receive(recvBuffer, recvBufferSize)) {
		//dbg("Received %s", recvBuffer)

		// process ping command
		if (strncmp(recvBuffer, "ping", recvBufferSize) == 0) {
			isOnline = true;
			pingTimer.sleep(PING_TIMEOUT_MS);
			masterBoard.blinkInfoLed(30);
			masterBoard.setErrorLed(false);
			char buf[32];
			snprintf(buf, 32, "%s pong", masterBoardIdStr);
			send(buf);
		}
	}

	// process ping timeout - possible connection lost - turn everything off immediately
	if (pingTimer.isOver()) {
		dbgn("No ping - connection lost?");
		isOnline = false;
		pingTimer.sleep(PING_TIMEOUT_MS);
		masterBoard.setErrorLed(true);
		if (failedPings++ > 10) {
			dbgn("No ping for a long time, trying to reset the device");
			delay(5000);
			uglyResetTheBoard();
		}
	}

	masterBoard.loop();
}

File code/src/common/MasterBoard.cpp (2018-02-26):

#include "MasterBoard.h"
#include <Arduino.h>
#include "Globals.h"
#include "dbg.h"
#include "../mega_board_id.h"

MasterBoard::MasterBoard() {
#ifdef __AVR_ATmega328P__
	//read address dip switch
	pinMode(DIP_PIN1, INPUT_PULLUP);
	pinMode(DIP_PIN2, INPUT_PULLUP);
	pinMode(DIP_PIN3, INPUT_PULLUP);
	if (!digitalRead(DIP_PIN1)) {
		this->id |= 1;
	}
	if (!digitalRead(DIP_PIN2)) {
		this->id |= 2;
	}
	if (!digitalRead(DIP_PIN3)) {
		this->id |= 4;
	}
#else
	this->id = MEGA_BOARD_ID;
#endif
	pinMode(INFO_LED_PIN, OUTPUT);
	digitalWrite(INFO_LED_PIN, LOW);
	pinMode(ERROR_LED_PIN, OUTPUT);
	digitalWrite(ERROR_LED_PIN, LOW);

}

int MasterBoard::getId() {
	return id;
}

void MasterBoard::setErrorLed(bool value) {
	digitalWrite(ERROR_LED_PIN, value ? HIGH : LOW);
}

void MasterBoard::setInfoLed(bool value) {
	digitalWrite(INFO_LED_PIN, value ? HIGH : LOW);
}

void MasterBoard::blinkInfoLed(int timeMs) {
	digitalWrite(INFO_LED_PIN, HIGH);
	blueLedTimer.sleep(timeMs);
}

void MasterBoard::initBlink() {
	bool blink = true;
	for (int i = 0; i < 10; i++) {
		setInfoLed(blink);
		setErrorLed(!blink);
		blink = !blink;
		delay(50);
	}
	setInfoLed(false);
	setErrorLed(false);
}

void MasterBoard::loop() {

	if (blueLedTimer.isOver()) {
		digitalWrite(INFO_LED_PIN, LOW);
	}

}

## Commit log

2017-01-05 moved stuff from railduino-udp repo
    [induino.sch, relayduino.sch, relayduino_shield.sch]
2017-01-08 generated first gerbers
    [relayduino - Bottom Copper (Paste).gbr, relayduino - Bottom Copper.gbr, relayduino - Bottom Solder Mask.gbr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]
2017-01-15 started new board based on shift registers with arduino nano
    [relayduino_nano_shift.sch]
2017-01-16 rewiring cascade
    [relayduino_nano_shift.sch]
2017-01-17 maybe better wiring
    [relayduino_nano_shift.sch]
2017-01-17 second try
    [relayduino_nano_shift.sch]
2017-01-18 added capacitor to latch bus
    [relayduino_nano_shift.sch]
2017-01-19 rewired +5V - using +5V stabilisation on arduino
    [relayduino_nano_shift.sch]
2017-01-19 add try to better wiring
    [relayduino_nano_shift.sch]
2017-01-23 added status led
    [relayduino_nano_shift.sch]
2017-02-12 extending to 64 ports
    [relayduino_nano_shift.sch]
2017-02-12 finishing design
    [relayduino_nano_shift.sch]
2017-03-21 moved old stuff
    [relayduino - Bottom Copper (Paste).gbr, relayduino - Bottom Copper.gbr, relayduino - Bottom Solder Mask.gbr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]
2017-03-21 added capacitor
    [nano_shift_2.sch]
2017-03-22 moved to pcbolny
    [induino-shift.sch]
2017-03-29 updated some components due to square pin1 of resistor arrays and nets
    [induino_shift_3.sch]
2017-03-29 deleted obsolete stuff
    [induino-shift.sch, induino.sch, induino_shift_3.sch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]
2017-03-29 removed old stuff, renamed actual work
    [nano_2803.sch, nano_shift_2.sch, nano_shift_3_controller.sch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]
2017-04-04 checked and fixed design rules, ready for pcb factory
2017-04-04 ready for pcb manufacture
    [induino_32x4021.sch]
2017-04-18 sent to pcb factory
    [56x595_2003a - Bottom Copper.gbr, 56x595_2003a - Drill Data - [Through Hole] (Unplated).drl, 56x595_2003a - Drill Data - [Through Hole].drl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]
2017-04-23 imported from private repo
    [16xMCP23017.sch, 56x595_2003a.sch, Configuration.h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]
2017-05-13 added capacitors due to 595 randomness when relays kicks backs
    [56x595_2003a.sch]
2017-05-13 fixed 24V kickback
    [16xMCP23017.sch]
2017-05-18 595 is dead, welcome 23017
    [16xMCP23017.sch, 56x595_2003a.sch]
2017-05-23 poslane na plosnaky.cz
    [16xMCP23017 - Bottom Copper.gbr, 16xMCP23017 - Drill Data - [Through Hole].drl, 16xMCP23017 - Drill Ident Drawing - [Through Hole].gbr]
2017-05-24 vymena diod za integrovany usmernovac
    [i2cmega.sch]
2017-05-29 diodes strikes back
    [i2cmega.sch]
2017-05-29 bigger holes
2017-06-04 odoslane do vyroby
    [16xMCP23017 - Bottom Copper (Paste).gbr, 16xMCP23017 - Bottom Copper (Resist).gbr, 16xMCP23017 - Bottom Copper.gbr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]
2017-06-28 both relayduino and induino sent to seedstudo
    [16xMCP23017.sch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]
2017-07-30 something is fucked on shield board, assigning address statically
2017-08-01 moved dip switch to another pins because 52 and 50 are occupied by spi interface (fuck)
2017-08-01 i2cmaster - changed dipswitch pins after board fixed
2017-08-02 fixed led resistor value
2017-08-07 new fuse board
    [fusedin2.sch]
2017-08-15 added ping command - timeout will turn off all relays - possible connection lost detection
2017-08-26 fuseboard split to 4x fuse and 4x ptc
    [4xfuse.sch, 4xptc.sch]
2017-12-11 added wiring scheme
2017-12-17 misc renames, moves etc ...
    [16xMCP23017 - Board outline.gbr, 16xMCP23017 - Bottom Copper (Paste).gbr, 16xMCP23017 - Bottom Copper (Resist).gbr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]
2017-12-17 another renames
    [16xMCP23017 - Board outline.gbr, 16xMCP23017 - Bottom Copper (Paste).gbr, 16xMCP23017 - Bottom Copper (Resist).gbr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]
2018-02-07 added transils, different psu, some cosmetics...
    [nanoi2c.sch]
2018-02-07 finalizing first prototype
    [nanoi2c.sch]
2018-02-10 tester for completed input boards
2018-02-11 gerbers for first try
    [nanoi2c - Bottom Copper (Paste).gbr, nanoi2c - Bottom Copper (Resist).gbr, nanoi2c - Bottom Copper.gbr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]
2018-02-11 bigger distance between vcc and v5v
    [nanoi2c - Bottom Copper.gbr]
2018-02-11 even more bigger distance between vcc and v5v :D
    [nanoi2c - Bottom Copper.gbr]
2018-02-11 sent to plosnaky.cz
    [nanoi2c - Bottom Copper.gbr, nanoi2c - Drill Data - [Through Hole] (Unplated).drl, nanoi2c - Drill Data - [Through Hole].drl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]
2018-02-17 initial led blink
2018-02-18 3pin dip switch due to D4 occupied by wiznet shield
    [learn.kicad_pcb, learn.sch]
2018-03-08 added BOM
2018-03-08 fixed 3d models for jst connectors and to220
    [i2cMaster.kicad_pcb, i2cMaster.sch]
2018-03-08 removed old designspark project
    [nanoi2c.sch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]
2018-03-08 little fix of 5v net
    [i2cMaster.kicad_pcb]
2018-03-09 sent to seedstudio
    [i2cMaster.kicad_pcb]
2018-10-04 fixed wiring diagram
2021-03-05 old schematics from designspark
